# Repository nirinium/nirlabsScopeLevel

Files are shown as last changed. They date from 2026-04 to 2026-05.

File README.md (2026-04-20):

# nirlabs Scope Level

An ESP32-based anti-cant level for rifle scopes. Uses an ADXL345 accelerometer to detect tilt and provides real-time LED feedback so you know when your rifle is level before taking a shot.

## Features

- **Three-zone indication** — Level (green), Near-level (green fade + red flash), and Cant (red heartbeat double-pulse)
- **Directional feedback** — Left or right red LED indicates which way you're canted
- **Hysteresis** — Prevents flickering at zone boundaries
- **EMA filtering** — Exponential moving average smooths sensor noise
- **Auto-calibration** — Calibrates on boot assuming the device is held level
- **Battery monitoring** — Low-battery warning via red LED double-blink every 5 seconds
- **Power management** — Enters light sleep after 1 minute at level to conserve battery

## Hardware

| Component | Pin |
|---|---|
| Green LED | GPIO 25 |
| Red LED (Left) | GPIO 26 |
| Red LED (Right) | GPIO 27 |
| Battery voltage divider | GPIO 34 (ADC) |
| ADXL345 SDA | GPIO 21 |
| ADXL345 SCL | GPIO 22 |

**Board:** NodeMCU-32S (ESP32)

## Zone Thresholds

| Zone | Range |
|---|---|
| Level (green solid) | < 0.5° |
| Near level (green fade + red pulse) | 0.5° – 1.5° |
| Cant (red heartbeat) | > 1.5° |

## Build

This project uses [PlatformIO](https://platformio.org/).

```bash
# Build
pio run

# Upload
pio run --target upload

# Serial monitor
pio device monitor
```

### Dependencies

- `Adafruit Unified Sensor` ^1.1.15
- `Adafruit ADXL345` ^1.3.4

## Configuration

Key constants in `src/main.cpp`:

| Constant | Default | Description |
|---|---|---|
| `THRESHOLD` | 0.5° | Dead-level zone boundary |
| `NEAR_ZONE` | 1.5° | Near-level to cant boundary |
| `MAX_CANT` | 5.0° | Maximum urgency angle |
| `HYSTERESIS` | 0.15° | Zone boundary flicker prevention |
| `EMA_ALPHA` | 0.4 | Filter smoothing (lower = smoother) |
| `SLEEP_TIMEOUT` | 60000 ms | Idle time before light sleep |
| `BATT_LOW` | 3.3 V | Low battery warning threshold |
| `DEBUG_MODE` | true | Serial debug output (set false for production) |

## License

NIRINIUM|LABS

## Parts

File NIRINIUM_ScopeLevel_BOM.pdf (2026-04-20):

# NIRINIUM|LABS

## Anti-Cant Scope Level - Bill of Materials Rev 2.0 | XIAO SAMD21 Build

# | Component | Qty | Specification | Est. Cost

1 | Seeeduino XIAO SAMD21 | 1 | ARM Cortex-M0+, USB-C, 3.3V | $5.40
2 | ADXL345 Breakout Board | 1 | I2C 3-axis accelerometer, 3.3V | $3.50
3 | Green LED (3mm) | 1 | Diffused, 20mA, ~2.0V Vf | $0.10
4 | Red LED (3mm) | 2 | Diffused, 20mA, ~1.8V Vf | $0.20
5 | Resistor 56 Ohm | 1 | 1/4W, for green LED | $0.05
6 | Resistor 68 Ohm | 2 | 1/4W, for red LEDs | $0.05
7 | Resistor 100K Ohm | 2 | 1/4W, battery voltage divider | $0.05
8 | LiPo Battery | 1 | 3.7V 250mAh (502030 pouch cell) | $4.00
9 | Slide Switch (SPDT) | 1 | Power on/off | $0.30
10 | Perfboard | 1 | 2x3cm or Seeed XIAO ProtoBoard | $1.50
11 | Female Pin Headers | 1 | 7-pin x 2 strips (for XIAO socket) | $0.30
12 | Hookup Wire (30AWG) | ~15cm | Silicone or Kynar | $0.10
TOTAL | | | | $15.55

## Optional Components

Component | Purpose | Est. Cost
JST-PH 2-pin connector | Clean battery disconnect | $0.50
Heat shrink tubing | Waterproofing connections | $1.00
Conformal coating spray | Weather/moisture protection | $8.00
Picatinny rail clamp | Scope mount (3D print or aluminum) | Varies

## Wiring Diagram

XIAO Pin -> Component
D4 (SDA) | -> ADXL345 SDA
D5 (SCL) | -> ADXL345 SCL
D1 | -> 56 Ohm -> Green LED -> GND
D2 | -> 68 Ohm -> Red Left -> GND
D3 | -> 68 Ohm -> Red Right -> GND
A0 | -> Voltage divider midpoint
| (100K from BAT+, 100K to GND)
3V3 | -> ADXL345 VCC
GND | -> ADXL345 GND, LEDs, divider
BAT pads | -> LiPo+ (via slide switch)

# NIRINIUM|LABS

## Anti-Cant Scope Level - Bill of Materials Rev 2.0 | XIAO SAMD21 Build

## Notes

- XIAO SAMD21 has built-in LiPo charger on BAT pads (charges via USB-C)
- Voltage divider: 100K + 100K gives ratio of 2.0 (set BATT_DIVIDER = 2.0)
- Hold device level during first 2 seconds after power-on for calibration
- Set DEBUG_MODE = false in firmware for production (removes serial output)
- Total current draw: ~15mA active, <0.5mA in sleep mode
- Estimated battery life with 250mAh: 12-16 hours continuous, weeks with sleep

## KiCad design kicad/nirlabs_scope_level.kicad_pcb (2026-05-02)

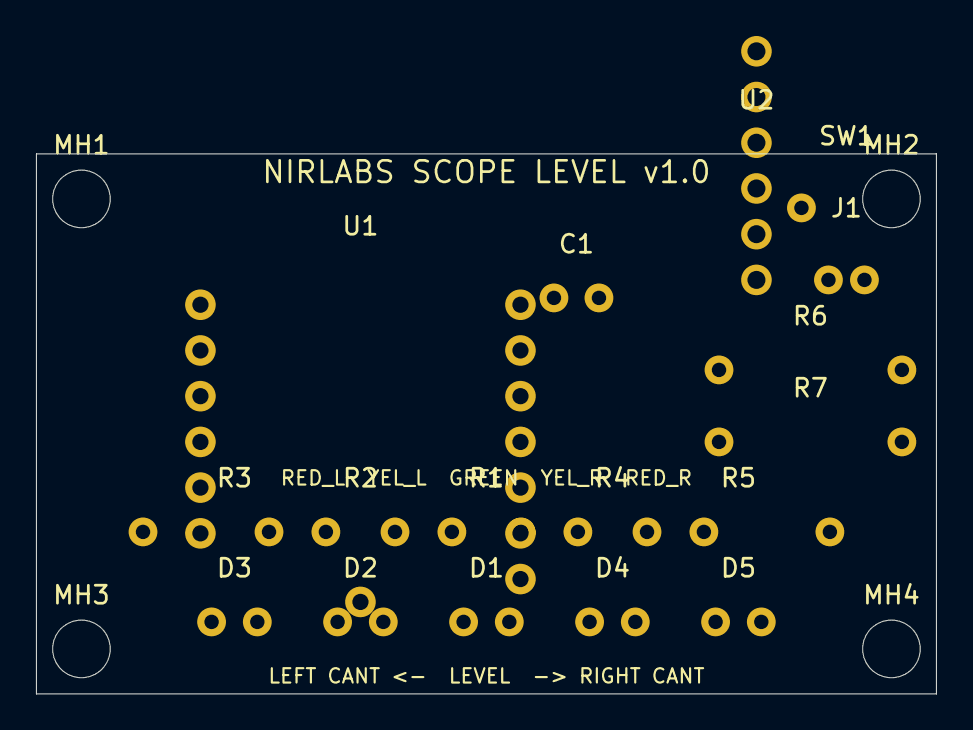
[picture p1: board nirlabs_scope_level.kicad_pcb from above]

Board: 2 copper layers, 50.0 x 30.0 mm, 21 parts (0 on the bottom side), 17 nets, no tracks yet.

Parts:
C1: 100nF; C_Disc_D3.0mm_W1.6mm_P2.50mm
D1: LED_GREEN; LED_D3.0mm
D2: LED_YEL_L; LED_D3.0mm
D3: LED_RED_L; LED_D3.0mm
D4: LED_YEL_R; LED_D3.0mm
D5: LED_RED_R; LED_D3.0mm
J1: LiPo_JST_PH; JST_PH_S2B-PH-K_1x02_P2.00mm_Horizontal
MH1, MH2, MH3, MH4: MH_3.2mm; MountingHole_3.2mm_M3
R1, R2, R3, R4, R5: 100R; R_Axial_DIN0207_L6.3mm_D2.5mm_P10.16mm_Horizontal
R6, R7: 100k; R_Axial_DIN0207_L6.3mm_D2.5mm_P10.16mm_Horizontal
SW1: Power_Slide_SW; SW_Slide_1P2T_CK_OS102011MA1QN1
U1: XIAO_ESP32C3
U2: ADXL345_Breakout; PinHeader_1x06_P2.54mm_Vertical

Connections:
+3V3: C1.1, U1.7, U2.1, U2.3
GND: C1.2, D1.1, D2.1, D3.1, D4.1, D5.1, J1.2, R7.2, U1.8, U1.14, U2.2
GPIO2_BATT: R6.2, R7.1, U1.1
GPIO3_RL: R3.1, U1.2
GPIO4_YR: R4.1, U1.3
GPIO5_RR: R5.1, U1.4
GPIO6_SDA: U1.5, U2.5
GPIO7_SCL: U1.6, U2.6
GPIO10_SW: SW1.2, U1.13
GPIO20_YL: R2.1, U1.10
GPIO21_GR: R1.1, U1.9
LED_GREEN_A: D1.2, R1.2
LED_RL_A: D3.2, R3.2
LED_RR_A: D5.2, R5.2
LED_YL_A: D2.2, R2.2
LED_YR_A: D4.2, R4.2
VBATT: J1.1, R6.1, SW1.1

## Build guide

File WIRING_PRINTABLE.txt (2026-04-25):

NIRLABS SCOPE LEVEL - EASY WIRING SHEET (BREADBOARD)
Target: Seeed Studio XIAO ESP32C3 + ADXL345 + 5 LEDs
Features: deep sleep, shake-awake via ADXL INT1, battery monitor

If you are new to wiring, follow this in order and do NOT skip steps.

============================================================
0) WHAT THE WORDS MEAN (QUICK)
============================================================
- 3V3 = 3.3V power pin
- GND = ground
- GPIO = a controllable signal pin
- LED anode = long leg (+)
- LED cathode = short leg (-, usually flat side on LED body)

Rule to remember:
GPIO pin -> resistor -> LED long leg
LED short leg -> GND

============================================================
1) PARTS CHECKLIST
============================================================
[ ] 1x XIAO ESP32C3
[ ] 1x ADXL345 module (must have INT1 pin broken out)
[ ] 5x LEDs (2 red, 2 yellow, 1 green)
[ ] 5x resistors (220 ohm to 330 ohm)
[ ] Breadboard + jumper wires
[ ] 1x SPST on/off switch (for hard power cut)
[ ] Optional 1x SPST switch (for soft standby on D10)
[ ] Optional battery divider: 2x 100k resistors

============================================================
2) PIN MAP (COPY EXACTLY)
============================================================
ADXL345 connections:
- XIAO 3V3        -> ADXL345 VCC  (TB2 RED)
- XIAO GND        -> ADXL345 GND (TB1 GREEN)
- XIAO D4 (GPIO6) -> ADXL345 SDA  (TB5 BLACK)
- XIAO D5 (GPIO7) -> ADXL345 SCL (TB6 RED)
- XIAO 3V3        -> ADXL345 CS  (TB3 WHITE)
- XIAO GND        -> ADXL345 SDO (TB4 BLUE)
- XIAO D9 (GPIO?) -> ADXL345 INT1        *** SHAKE-AWAKE WIRE ***
  (INT2 can be left unconnected)

LED connections (each through its own resistor):
- XIAO D1 (GPIO3)  -> resistor -> RED LEFT long leg
- XIAO D7 (GPIO20) -> resistor -> YELLOW LEFT long leg
- XIAO D6 (GPIO21) -> resistor -> GREEN CENTER long leg
- XIAO D2 (GPIO4)  -> resistor -> YELLOW RIGHT long leg
- XIAO D3 (GPIO5)  -> resistor -> RED RIGHT long leg
- All LED short legs -> GND rail

Optional battery sense (only if you are using battery monitoring):
- Battery + -> 100k -> ADC NODE -> 100k -> GND
- ADC NODE -> XIAO A0/D0 (GPIO2)
- Battery - -> GND

Optional soft standby switch (firmware controlled):
- XIAO D10 (GPIO10) -> one switch leg
- Other switch leg -> GND
- Switch OPEN = RUN, switch CLOSED = standby sleep

Recommended hard power switch (real OFF):
- Battery + -> hard switch -> system VIN/5V input
- Battery - -> system GND
- This fully disconnects power and gives best battery life

============================================================
3) BREADBOARD LAYOUT (LEFT TO RIGHT)
============================================================
LED order must be:
RED-L   YEL-L   GREEN   YEL-R   RED-R

Put all 5 LED short legs toward the same side so grounding is easy.

============================================================
4) STEP-BY-STEP BUILD
============================================================
Step 1:
Put the XIAO on the breadboard so pins are easy to reach.

Step 2:
Pick one rail as GND and one rail as 3V3.
Wire XIAO GND to GND rail.
Wire XIAO 3V3 to 3V3 rail.
-
Step 3:
Place ADXL345 on the board.
Wire VCC and GND first.

Step 4:
Wire ADXL345 mode pins:
CS to 3V3, SDO to GND.

Step 5:
Wire I2C:
D4 -> SDA, D5 -> SCL.

Step 5b (SHAKE-AWAKE - required for deep sleep wake-up):
Wire ADXL345 INT1 -> XIAO D8 (GPIO8).
Do NOT use INT2 for this. Only INT1 is connected to firmware.
No resistor needed on this line.

Step 6:
Place 5 LEDs in this order:
RED-L, YEL-L, GREEN, YEL-R, RED-R.

Step 7:
For each LED:
Connect one resistor from its GPIO pin to the LED long leg.
Connect LED short leg to GND rail.

Step 8 (optional battery input):
Build the 100k/100k divider and connect midpoint to GPIO2.

Step 9 (recommended hard OFF switch):
Put the switch in series with battery positive.
Example: Battery + -> switch -> board power input.

Step 10 (optional soft standby switch):
Wire D10 to switch, and switch to GND.
OPEN = run, CLOSED = standby sleep.

============================================================
5) STOP-AND-CHECK BEFORE POWER
============================================================
[ ] Every LED has a resistor in series
[ ] Every LED short leg goes to GND
[ ] ADXL345 VCC is 3.3V (NOT 5V)
[ ] ADXL345 CS is tied to 3V3
[ ] ADXL345 SDO is tied to GND
[ ] SDA is on D4 and SCL is on D5
[ ] ADXL345 INT1 is wired to D8 (GPIO8) - shake-awake
[ ] All grounds are common
[ ] Hard power switch is in series with battery + (if used)
[ ] Soft switch on D10 goes only to GND (if used)

If any box is unchecked, do not power yet.

============================================================
6) FIRST POWER TEST
============================================================
1. Power the board.
2. Open serial monitor at 115200.
3. You should see I2C scan find device at 0x53.

If you do not see 0x53:
- Recheck SDA/SCL are not swapped.
- Recheck CS and SDO straps.
- Recheck ADXL345 power and ground.

============================================================
7) DEEP SLEEP BEHAVIOR
============================================================
After 60 seconds of the scope sitting perfectly level, the XIAO
enters deep sleep. The USB port disappears - this is normal.

To wake:
- Pick up or move the scope - the ADXL345 detects the motion
  and pulses INT1 HIGH, which wakes the XIAO via D8 (GPIO8).

Calibration is preserved in RTC memory across sleep cycles.
The device will NOT re-run the calibration routine on wake,
only on a true cold boot (first power-on after full power loss).

If the device is not waking on movement:
- Confirm INT1 (not INT2) is wired to D8.
- Try moving the scope more firmly - threshold is ~250 mg (1/4g).
- Threshold is tunable: see ACCEL_ACTIVITY_THRESHOLD in firmware.

============================================================
8) COMMON FIXES
============================================================
Problem: Left/right is backwards
Fix: Swap only left and right LED signal wires.

Problem: LED too bright
Fix: Use bigger resistor (330 to 470 ohm).

Problem: LED too dim
Fix: Use 220 ohm and verify correct LED leg orientation.

Problem: Board never fully turns off
Fix: Use the hard power switch in battery + line. Soft switch is standby, not true off.

============================================================
END OF EASY SHEET
============================================================

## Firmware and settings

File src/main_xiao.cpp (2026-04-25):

#include <Arduino.h>
#include <Wire.h>
#include <Adafruit_Sensor.h>
#include <Adafruit_ADXL345_U.h>
#include <esp_sleep.h>

Adafruit_ADXL345_Unified accel = Adafruit_ADXL345_Unified(12345);
// === RTC-RETAINED STATE (survives deep sleep) ===
RTC_DATA_ATTR static int     bootCount           = 0;
RTC_DATA_ATTR static float   rtcCalibrationOffset = 0.0f;
RTC_DATA_ATTR static bool    rtcCalibrated        = false;

// === PIN ASSIGNMENTS (Seeed Studio XIAO ESP32C3) ===
const int GREEN_LED    = 21; // D6
const int YELLOW_LEFT  = 20; // D7
const int RED_LEFT     = 3;  // D1
const int YELLOW_RIGHT = 4;  // D2
const int RED_RIGHT    = 5;  // D3
const int BATT_PIN     = 2;  // A0/D0
const int POWER_SW_PIN = 10; // D10, optional SPST to GND for standby

// === I2C PINS (XIAO ESP32C3) ===
const int I2C_SDA = 6; // D4
const int I2C_SCL = 7; // D5

// === PWM CHANNELS (ESP32 LEDC) ===
const int PWM_CH_GREEN = 0;
const int PWM_CH_YL    = 1;
const int PWM_CH_RL    = 2;
const int PWM_CH_YR    = 3;
const int PWM_CH_RR    = 4;
const int PWM_FREQ     = 5000; // 5kHz
const int PWM_RES      = 8;    // 8-bit (0-255)

// === ZONE THRESHOLDS ===
const float THRESHOLD  = 0.5;  // degrees: dead-level zone
const float NEAR_ZONE  = 1.5;  // degrees: almost-level transition
const float MAX_CANT   = 5.0;  // degrees: maximum urgency
const float HYSTERESIS = 0.15; // degrees: prevents boundary flicker

// === HEARTBEAT TIMING ===
const int FLASH_ON  = 80;   // ms
const int FLASH_GAP = 100;  // ms
const int CYCLE_MIN = 500;  // ms
const int CYCLE_MAX = 1500; // ms

// === FILTER ===
const float EMA_ALPHA = 0.4; // lower = smoother

// === BATTERY MONITORING ===
const float BATT_LOW = 3.3;                         // volts
const float BATT_DIVIDER = 2.0;                     // 100k/100k divider
const unsigned long BATT_CHECK_INTERVAL = 10000UL;  // ms

// === POWER MANAGEMENT ===
const unsigned long SLEEP_TIMEOUT  = 60000UL;  // ms of level-idle before deep sleep
const int ACCEL_INT_PIN            = 9;        // D9 / GPIO9 — wire ADXL345 INT1 here
const bool ENABLE_DEEP_SLEEP       = false;    // set falserely on physical battery switch for power-off

// === ADXL345 ACTIVITY INTERRUPT (shake-awake) ===
// Each LSB of THRESH_ACT = 62.5 mg. 4 = 250 mg — adjust for sensitivity.
const uint8_t ACCEL_ACTIVITY_THRESHOLD = 4;
static constexpr uint8_t ADXL_ADDR_CUSTOM = 0x53;
static constexpr uint8_t ADXL_REG_THRESH_ACT_CUSTOM = 0x24;
static constexpr uint8_t ADXL_REG_ACT_INACT_CTL_CUSTOM = 0x27;
static constexpr uint8_t ADXL_REG_INT_ENABLE_CUSTOM = 0x2E;
static constexpr uint8_t ADXL_REG_INT_MAP_CUSTOM = 0x2F;
static constexpr uint8_t ADXL_REG_INT_SOURCE_CUSTOM = 0x30;

// === DEBUG ===
const bool DEBUG_MODE = true;
const bool USE_SOFT_POWER_SWITCH = false;

// === STATE ===
unsigned long cycleStart = 0;
int currentCycle = CYCLE_MAX;
float filteredRoll = 0.0;
float calibrationOffset = 0.0;
int currentZone = 0; // 0=level, 1=near, 2=cant
unsigned long lastActivity = 0;
unsigned long lastBattCheck = 0;
bool batteryLow = false;
bool firstReading = true;
unsigned long lastDebugPrint = 0;
const unsigned long DEBUG_PRINT_INTERVAL = 200UL;

void ledPWM(int channel, uint8_t brightness);
void allLedsOff();

// --- ADXL345 low-level register access (bypasses library to reach INT regs) ---
static void adxlWriteReg(uint8_t reg, uint8_t value) {
  Wire.beginTransmission(ADXL_ADDR_CUSTOM);
  Wire.write(reg);
  Wire.write(value);
  Wire.endTransmission();
}

static uint8_t adxlReadReg(uint8_t reg) {
  Wire.beginTransmission(ADXL_ADDR_CUSTOM);
  Wire.write(reg);
  if (Wire.endTransmission(false) != 0) {
    return 0;
  }
  const uint8_t requested = Wire.requestFrom(static_cast<uint8_t>(ADXL_ADDR_CUSTOM), static_cast<uint8_t>(1));
  if (requested != 1 || !Wire.available()) {
    return 0;
  }
  return Wire.read();
}

// Arm ADXL345 activity interrupt so INT1 goes HIGH on shake.
// Call this just before entering deep sleep.
void setupAccelActivityInterrupt() {
  adxlWriteReg(ADXL_REG_THRESH_ACT_CUSTOM,    ACCEL_ACTIVITY_THRESHOLD);
  adxlWriteReg(ADXL_REG_ACT_INACT_CTL_CUSTOM, 0xFF); // AC-coupled, all axes
  adxlWriteReg(ADXL_REG_INT_MAP_CUSTOM,       0x00); // all interrupts -> INT1
  adxlWriteReg(ADXL_REG_INT_ENABLE_CUSTOM,    0x10); // Activity interrupt enable
  adxlReadReg(ADXL_REG_INT_SOURCE_CUSTOM);           // clear any stale interrupt
}

bool handleSoftPowerSwitch() {
  if (!USE_SOFT_POWER_SWITCH) return false;

  // Switch wiring: D10 to GND when OFF, internal pull-up keeps it HIGH when ON.
  if (digitalRead(POWER_SW_PIN) == LOW) {
    allLedsOff();
    if (DEBUG_MODE) {
      Serial.println("Power switch OFF -> standby sleep");
      Serial.flush();
    }
    esp_sleep_enable_timer_wakeup(2000000UL);
    esp_light_sleep_start();
    firstReading = true;
    return true;
  }
  return false;
}

float readBatteryVoltage() {
  int raw = analogRead(BATT_PIN);
  return (raw / 4095.0f) * 3.3f * BATT_DIVIDER;
}

void calibrate() {
  Serial.println("Calibrating... hold level!");
  float sum = 0.0;
  const int samples = 50;
  for (int i = 0; i < samples; i++) {
    sensors_event_t event;
    accel.getEvent(&event);
    sum += atan2(event.acceleration.y, event.acceleration.z) * 180.0f / PI;
    
    // Flash all LEDs during calibration to show progress
    bool ledOn = (i % 10) < 5; // alternate every ~100ms
    uint8_t brightness = ledOn ? 150 : 0;
    ledPWM(PWM_CH_GREEN, brightness);
    ledPWM(PWM_CH_YL, brightness);
    ledPWM(PWM_CH_RL, brightness);
    ledPWM(PWM_CH_YR, brightness);
    ledPWM(PWM_CH_RR, brightness);
    
    delay(20);
  }
  calibrationOffset = sum / samples;
  rtcCalibrationOffset = calibrationOffset;
  rtcCalibrated = true;
  allLedsOff();
  Serial.printf("Calibration offset: %.2f\n", calibrationOffset);
}

int getZoneWithHysteresis(float absRoll, int prevZone) {
  switch (prevZone) {
    case 0: // LEVEL
      if (absRoll >= THRESHOLD + HYSTERESIS) {
        return (absRoll >= NEAR_ZONE + HYSTERESIS) ? 2 : 1;
      }
      return 0;
    case 1: // NEAR
      if (absRoll < THRESHOLD - HYSTERESIS) return 0;
      if (absRoll >= NEAR_ZONE + HYSTERESIS) return 2;
      return 1;
    case 2: // CANT
      if (absRoll < NEAR_ZONE - HYSTERESIS) {
        return (absRoll < THRESHOLD - HYSTERESIS) ? 0 : 1;
      }
      return 2;
  }
  return 0;
}

void ledPWM(int channel, uint8_t brightness) {
  ledcWrite(channel, brightness);
}

void allLedsOff() {
  ledPWM(PWM_CH_GREEN, 0);
  ledPWM(PWM_CH_YL, 0);
  ledPWM(PWM_CH_RL, 0);
  ledPWM(PWM_CH_YR, 0);
  ledPWM(PWM_CH_RR, 0);
}

void enterDeepSleep() {
  allLedsOff();
  setupAccelActivityInterrupt(); // arm ADXL shake-wake before cutting power
  if (DEBUG_MODE) {
    Serial.println("Entering deep sleep. Move scope to wake (ADXL INT1 on D8).");
    Serial.flush();
  }
  // INT1 is active-HIGH; wake when it goes high on movement
  esp_deep_sleep_enable_gpio_wakeup(BIT(ACCEL_INT_PIN), ESP_GPIO_WAKEUP_GPIO_HIGH);
  esp_deep_sleep_start();
}

void setup() {
  Serial.begin(115200);
  delay(1000);

  ++bootCount;
  Serial.println("NIRINIUM|LABS");
  Serial.println("Anti-Cant Level XIAO ESP32C3");
  Serial.printf("Boot #%d\n", bootCount);

  if (ENABLE_DEEP_SLEEP) {
    esp_sleep_wakeup_cause_t wakeReason = esp_sleep_get_wakeup_cause();
    if (wakeReason == ESP_SLEEP_WAKEUP_GPIO) {
      Serial.println("Woke from deep sleep via movement (ADXL shake-awake).");
    } else {
      Serial.println("Cold boot.");
    }
  } else {
    Serial.println("Deep sleep disabled. Use battery switch for power-off.");
  }

  ledcSetup(PWM_CH_GREEN, PWM_FREQ, PWM_RES);
  ledcSetup(PWM_CH_YL, PWM_FREQ, PWM_RES);
  ledcSetup(PWM_CH_RL, PWM_FREQ, PWM_RES);
  ledcSetup(PWM_CH_YR, PWM_FREQ, PWM_RES);
  ledcSetup(PWM_CH_RR, PWM_FREQ, PWM_RES);

  ledcAttachPin(GREEN_LED, PWM_CH_GREEN);
  ledcAttachPin(YELLOW_LEFT, PWM_CH_YL);
  ledcAttachPin(RED_LEFT, PWM_CH_RL);
  ledcAttachPin(YELLOW_RIGHT, PWM_CH_YR);
  ledcAttachPin(RED_RIGHT, PWM_CH_RR);

  analogReadResolution(12);
  pinMode(BATT_PIN, INPUT);
  pinMode(POWER_SW_PIN, INPUT_PULLUP);
  if (ENABLE_DEEP_SLEEP) {
    pinMode(ACCEL_INT_PIN, INPUT); // ADXL INT1 input (no pull — driven by ADXL)
  }

  Wire.begin(I2C_SDA, I2C_SCL);

  if (DEBUG_MODE) {
    Serial.println("Scanning I2C...");
    byte count = 0;
    for (byte addr = 1; addr < 127; addr++) {
      Wire.beginTransmission(addr);
      if (Wire.endTransmission() == 0) {
        Serial.printf("  Found device at 0x%02X\n", addr);
        count++;
      }
    }
    Serial.printf("I2C scan done, %d device(s) found.\n", count);
  }

  if (!accel.begin()) {
    Serial.println("ADXL345 not found! Check wiring.");
    while (1) {
      ledPWM(PWM_CH_YL, 220);
      ledPWM(PWM_CH_RL, 220);
      ledPWM(PWM_CH_YR, 220);
      ledPWM(PWM_CH_RR, 220);
      delay(200);
      allLedsOff();
      delay(200);
    }
  }

  accel.setRange(ADXL345_RANGE_2_G);
  if (ENABLE_DEEP_SLEEP) {
    // Clear any pending ADXL interrupt so INT1 goes low before we check the pin again
    adxlReadReg(ADXL_REG_INT_SOURCE_CUSTOM);

    esp_sleep_wakeup_cause_t wakeReasonForCal = esp_sleep_get_wakeup_cause();
    if (wakeReasonForCal == ESP_SLEEP_WAKEUP_GPIO && rtcCalibrated) {
      calibrationOffset = rtcCalibrationOffset;
      Serial.printf("Restored calibration offset: %.2f (skipping recal)\n", calibrationOffset);
    } else {
      calibrate();
    }
  } else {
    calibrate();
  }

  Serial.println("Anti-Cant Level ready!");
  lastActivity = millis();
}

void loop() {
  unsigned long now = millis();

  if (handleSoftPowerSwitch()) {
    return;
  }

  if (now - lastBattCheck >= BATT_CHECK_INTERVAL) {
    lastBattCheck = now;
    float voltage = readBatteryVoltage();
    batteryLow = (voltage < BATT_LOW && voltage > 0.5f);
    if (DEBUG_MODE && batteryLow) {
      Serial.printf("LOW BATTERY: %.2fV\n", voltage);
    }
  }

  sensors_event_t event;
  accel.getEvent(&event);

  float rawRoll = atan2(event.acceleration.y, event.acceleration.z) * 180.0f / PI;
  rawRoll -= calibrationOffset;

  if (firstReading) {
    filteredRoll = rawRoll;
    firstReading = false;
  } else {
    filteredRoll = EMA_ALPHA * rawRoll + (1.0f - EMA_ALPHA) * filteredRoll;
  }

  float roll = filteredRoll;
  float absRoll = fabs(roll);

  currentZone = getZoneWithHysteresis(absRoll, currentZone);

  if (currentZone != 0) {
    lastActivity = now;
  } else if (ENABLE_DEEP_SLEEP && (now - lastActivity >= SLEEP_TIMEOUT)) {
    enterDeepSleep(); // never returns — setup() runs on wake
  }

  unsigned long elapsed = now - cycleStart;

  if (currentZone == 0) {
    uint8_t greenBright = batteryLow ? 60 : 200;
    ledPWM(PWM_CH_GREEN, greenBright);
    ledPWM(PWM_CH_YL, 0);
    ledPWM(PWM_CH_RL, 0);
    ledPWM(PWM_CH_YR, 0);
    ledPWM(PWM_CH_RR, 0);
    cycleStart = now;

  } else if (currentZone == 1) {
    float t = (absRoll - THRESHOLD) / (NEAR_ZONE - THRESHOLD);
    t = constrain(t, 0.0f, 1.0f);
    currentCycle = CYCLE_MAX - (int)(t * t * (CYCLE_MAX - CYCLE_MIN) * 0.3f);

    if (elapsed >= (unsigned long)currentCycle) cycleStart = now;

    float phase = (float)elapsed / (float)currentCycle;
    uint8_t greenBright = (uint8_t)(100.0f + 100.0f * cos(phase * 2.0f * PI));
    ledPWM(PWM_CH_GREEN, greenBright);

    bool yellowOn = elapsed < (unsigned long)FLASH_ON;
    uint8_t yellowBright = yellowOn ? (uint8_t)(120 + 80 * t) : 0;

    ledPWM(PWM_CH_YL, (roll < 0) ? yellowBright : 0);
    ledPWM(PWM_CH_YR, (roll > 0) ? yellowBright : 0);
    ledPWM(PWM_CH_RL, 0);
    ledPWM(PWM_CH_RR, 0);

  } else {
    float t = constrain((absRoll - NEAR_ZONE) / (MAX_CANT - NEAR_ZONE), 0.0f, 1.0f);
    currentCycle = CYCLE_MAX - (int)(t * t * (CYCLE_MAX - CYCLE_MIN));

    if (elapsed >= (unsigned long)currentCycle) cycleStart = now;

    ledPWM(PWM_CH_GREEN, 0);

    bool pulse1 = elapsed < (unsigned long)FLASH_ON;
    bool pulse2 = elapsed >= (unsigned long)(FLASH_ON + FLASH_GAP)
               && elapsed <  (unsigned long)(FLASH_ON + FLASH_GAP + FLASH_ON);
    bool redOn = pulse1 || pulse2;

    uint8_t redBright = redOn ? (uint8_t)(150 + 105 * t) : 0;
    uint8_t yellowBright = (uint8_t)(25 + 80 * t);

    ledPWM(PWM_CH_YL, (roll < 0) ? yellowBright : 0);
    ledPWM(PWM_CH_RL, (roll < 0) ? redBright : 0);
    ledPWM(PWM_CH_YR, (roll > 0) ? yellowBright : 0);
    ledPWM(PWM_CH_RR, (roll > 0) ? redBright : 0);
  }

  if (batteryLow && (now % 5000UL) < 150UL) {
    ledPWM(PWM_CH_YL, 90);
    ledPWM(PWM_CH_RL, 90);
    ledPWM(PWM_CH_YR, 90);
    ledPWM(PWM_CH_RR, 90);
  }

  if (DEBUG_MODE && (now - lastDebugPrint >= DEBUG_PRINT_INTERVAL)) {
    const char* zoneName[] = {"LEVEL", "NEAR", "CANT"};
    Serial.printf("Roll: %.2f (raw: %.2f) [%s]\n", roll, rawRoll, zoneName[currentZone]);
    lastDebugPrint = now;
  }

  delay(25);
}

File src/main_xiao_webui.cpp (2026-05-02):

#include <Arduino.h>
#include <Wire.h>
#include <WiFi.h>
#include <esp_wifi.h>
#include <ESPAsyncWebServer.h>
#include <Adafruit_Sensor.h>
#include <Adafruit_ADXL345_U.h>
#include <ArduinoJson.h>
#include <esp_sleep.h>
#include <nvs_flash.h>
#include <nvs.h>

// ===== WiFi Config =====
const char* SSID = "NIRINIUM_LEVEL";
const char* PASSWORD = nullptr;
const char* NVS_NAMESPACE = "scopelevel";

// ===== Web Server =====
AsyncWebServer server(80);

// ===== Hardware =====
Adafruit_ADXL345_Unified accel = Adafruit_ADXL345_Unified(12345);

// === RTC-RETAINED STATE ===
RTC_DATA_ATTR static int bootCount = 0;
RTC_DATA_ATTR static float rtcCalibrationOffset = 0.0f;
RTC_DATA_ATTR static bool rtcCalibrated = false;

// === PIN ASSIGNMENTS ===
const int GREEN_LED    = 21; // D6
const int YELLOW_LEFT  = 20; // D7
const int RED_LEFT     = 3;  // D1
const int YELLOW_RIGHT = 4;  // D2
const int RED_RIGHT    = 5;  // D3
const int BATT_PIN     = 2;  // A0/D0
const int POWER_SW_PIN = 10; // D10

// === I2C PINS ===
const int I2C_SDA = 6; // D4
const int I2C_SCL = 7; // D5

// === PWM CHANNELS ===
const int PWM_CH_GREEN = 0;
const int PWM_CH_YL    = 1;
const int PWM_CH_RL    = 2;
const int PWM_CH_YR    = 3;
const int PWM_CH_RR    = 4;
const int PWM_FREQ     = 5000;
const int PWM_RES      = 8;

// === ZONE THRESHOLDS (configurable via web) ===
float THRESHOLD  = 0.5;
float NEAR_ZONE  = 1.5;
float MAX_CANT   = 5.0;
float HYSTERESIS = 0.15;
float EMA_ALPHA  = 0.4;

// === LED BRIGHTNESS (0-255, configurable via web) ===
uint8_t g_led_brightness = 200;

// === STATE ===
unsigned long cycleStart = 0;
int currentCycle = 1500;
float filteredRoll = 0.0;
float calibrationOffset = 0.0;
int currentZone = 0;
float currentRoll = 0.0;
unsigned long lastBattCheck = 0;
float currentBattVoltage = 0.0f;
bool batteryLow = false;
bool firstReading = true;
bool calibrating = false;

void ledPWM(int channel, uint8_t brightness) {
  ledcWrite(channel, brightness);
}

void allLedsOff() {
  ledPWM(PWM_CH_GREEN, 0);
  ledPWM(PWM_CH_YL, 0);
  ledPWM(PWM_CH_RL, 0);
  ledPWM(PWM_CH_YR, 0);
  ledPWM(PWM_CH_RR, 0);
}

// Calibration: set to (actual_V / displayed_V) if reading is still off
#define BATT_CALIB_RATIO 1.0f

float readBatteryVoltage() {
  // Use raw analogRead — at 11dB (set via adc1_config_channel_atten), full scale = 2500mV
  // analogReadMilliVolts() is unreliable when attenuation is set via IDF directly
  uint32_t sum = 0;
  for (int i = 0; i < 8; i++) sum += analogRead(BATT_PIN);
  float raw = sum / 8.0f;
  float pinV = (raw / 4095.0f) * 2.5f;  // 11dB attenuation: 0-2.5V full scale
  return pinV * 2.0f * BATT_CALIB_RATIO; // 100k/100k divider: D0 = BAT+/2
}

void calibrate() {
  calibrating = true;
  float sum = 0.0;
  const int samples = 50;
  for (int i = 0; i < samples; i++) {
    sensors_event_t event;
    accel.getEvent(&event);
    sum += atan2(event.acceleration.y, event.acceleration.z) * 180.0f / PI;
    
    bool ledOn = (i % 10) < 5;
    uint8_t brightness = ledOn ? 150 : 0;
    ledPWM(PWM_CH_GREEN, brightness);
    ledPWM(PWM_CH_YL, brightness);
    ledPWM(PWM_CH_RL, brightness);
    ledPWM(PWM_CH_YR, brightness);
    ledPWM(PWM_CH_RR, brightness);
    delay(20);
  }
  calibrationOffset = sum / samples;
  rtcCalibrationOffset = calibrationOffset;
  rtcCalibrated = true;
  allLedsOff();
  calibrating = false;
  Serial.printf("Calibration offset: %.2f\n", calibrationOffset);
}

int getZoneWithHysteresis(float absRoll, int prevZone) {
  switch (prevZone) {
    case 0:
      if (absRoll >= THRESHOLD + HYSTERESIS) {
        return (absRoll >= NEAR_ZONE + HYSTERESIS) ? 2 : 1;
      }
      return 0;
    case 1:
      if (absRoll < THRESHOLD - HYSTERESIS) return 0;
      if (absRoll >= NEAR_ZONE + HYSTERESIS) return 2;
      return 1;
    case 2:
      if (absRoll < NEAR_ZONE - HYSTERESIS) {
        return (absRoll < THRESHOLD - HYSTERESIS) ? 0 : 1;
      }
      return 2;
  }
  return 0;
}

void saveThresholdsToNVS() {
  nvs_handle_t handle;
  nvs_open(NVS_NAMESPACE, NVS_READWRITE, &handle);
  nvs_set_i32(handle, "threshold_x100", (int32_t)(THRESHOLD * 100));
  nvs_set_i32(handle, "nearzone_x100", (int32_t)(NEAR_ZONE * 100));
  nvs_set_i32(handle, "maxcant_x100", (int32_t)(MAX_CANT * 100));
  nvs_set_i32(handle, "hysteresis_x100", (int32_t)(HYSTERESIS * 100));
  nvs_set_i32(handle, "ema_alpha_x1000", (int32_t)(EMA_ALPHA * 1000));
  nvs_set_i32(handle, "led_brightness", (int32_t)g_led_brightness);
  nvs_commit(handle);
  nvs_close(handle);
}

void loadThresholdsFromNVS() {
  nvs_handle_t handle;
  if (nvs_open(NVS_NAMESPACE, NVS_READONLY, &handle) == ESP_OK) {
    int32_t val;
    if (nvs_get_i32(handle, "threshold_x100", &val) == ESP_OK) THRESHOLD = val / 100.0f;
    if (nvs_get_i32(handle, "nearzone_x100", &val) == ESP_OK) NEAR_ZONE = val / 100.0f;
    if (nvs_get_i32(handle, "maxcant_x100", &val) == ESP_OK) MAX_CANT = val / 100.0f;
    if (nvs_get_i32(handle, "hysteresis_x100", &val) == ESP_OK) HYSTERESIS = val / 100.0f;
    if (nvs_get_i32(handle, "ema_alpha_x1000", &val) == ESP_OK) EMA_ALPHA = val / 1000.0f;
    if (nvs_get_i32(handle, "led_brightness", &val) == ESP_OK) g_led_brightness = (uint8_t)constrain(val, 0, 255);
    nvs_close(handle);
  }
}
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
